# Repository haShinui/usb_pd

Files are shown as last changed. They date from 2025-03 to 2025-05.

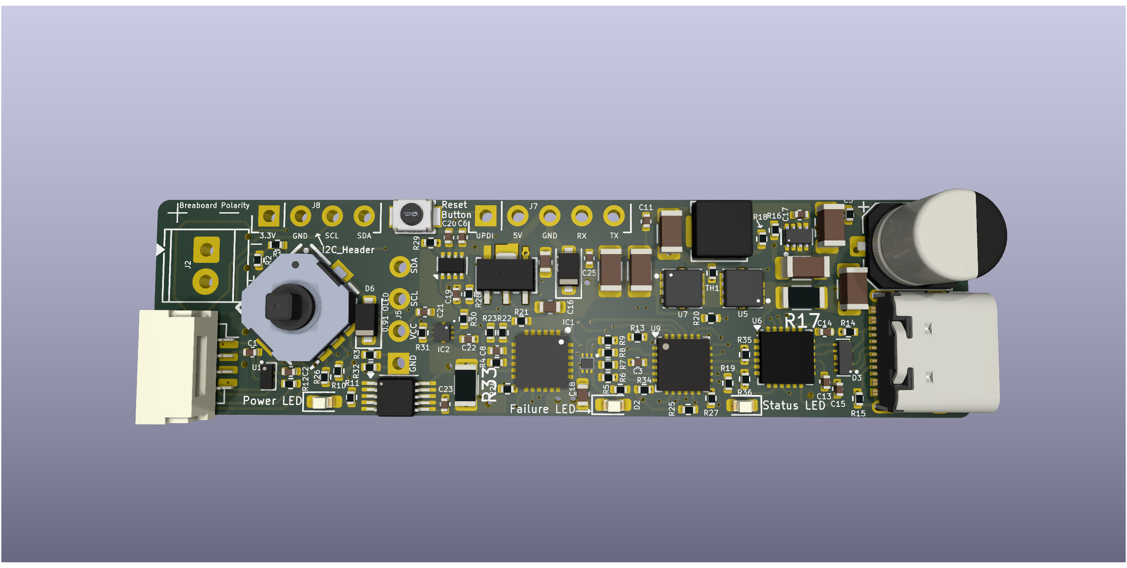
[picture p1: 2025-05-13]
KiCad Files/CYPD3177_DEV_BOARD/pictures/CYPD3177_3.3V_V2_+_OLED(top_no_comps).png

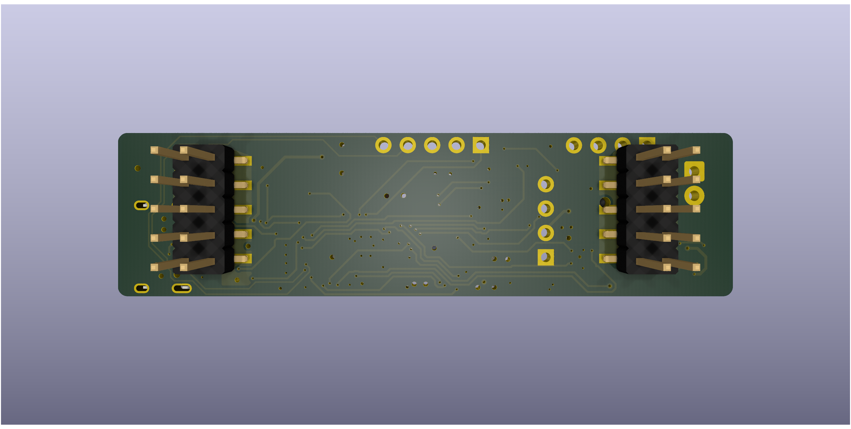
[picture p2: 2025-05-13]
KiCad Files/CYPD3177_DEV_BOARD/pictures/CYPD3177_3.3V_V2_+_OLED(bottom).png

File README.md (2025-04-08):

# BrodBoost-PD
This USB Power Delivery adapter allows to request 20V, 15V, 12V, 9V, or 5V from a compatible power supply, eliminating the need for bulky converters or multiple adapters. A DIP switch selects the desired voltage. The adapter features a power LED, a fault LED, and a screw terminal block for easy wiring. Compatible with standard 2.54 mm breadboards, it provides a simple, compact power solution for prototyping and development.

I documented the process and the design, if you wish to learn more or see earlier versions, I made a short YouTube Video bellow

https://www.youtube.com/watch?v=EAl_JSd1YsA

BrodBoost-PD is an open-source project of Axiometa. Device is available for purchase on the [official website](https://axiometa.ai/product/brodboost-pd/)

PD

# Overview

pdp_top-1

# Device Configurations
BrodBoost-PD can be acquired and/or assembled in essentially three majors ways.

1. No breadboard rails, No Screw Terminal - Great for compact and intergrated solutions.
2. No Breadboard rail, Screw Terminal - Great for all solutions, requires no soldering.
3. Breadboard rails, Screw Terminal - Amazinf for breadboards, allows prototyping and attaching some loads on terminal



# Breadboard Compatibility
In the case of attached headers,the device becomes compatible with almost all BB400 & BB800 Solderless Breadboards

compatibility_pdp1

# Voltage Selection
All voltage rails are connected, that includes both breadboard rails, screw terminal and solder pads. The voltages can be selected through the dip switches in a fashion shown bellow.

wdqqwd

# Schematic
A USB-C receptacle accepts a USB-C cable, with CC1 and CC2 pins connected to the CYPD3177. USB data lines are broken out to a header, while the power rails are managed through a MOSFET bridge, also controlled by the CYPD3177.
When a compatible USB-C cable is connected, the CYPD3177 communicates with the power source and requests a voltage based on the DIP switch-selected reference voltage. Available options include 20V, 15V, 12V, 9V, and 5V.
Current is fixed at 2A, as requested current does not enforce actual current delivery, making adjustable current selection unnecessary. I2C connections have been removed to save space and BOM cost, as they offer little added value for this application.



# PCB Design

BrodBoost-PD is a 4-layer PCB measuring 11.4 mm by 54.0 mm, designed to maximize trace width, thermal performance and interfere as minimally as possible to the power lines. This layout comfortably supports the nominal device current of approximately 4-5 A @ 20V.









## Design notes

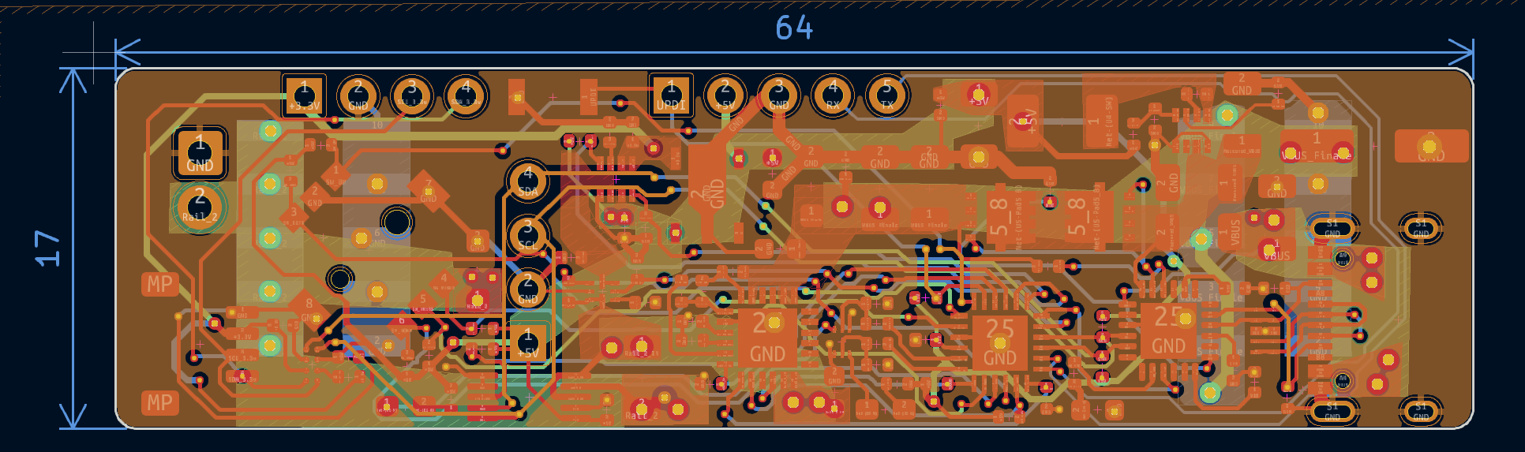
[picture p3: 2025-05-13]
KiCad Files/CYPD3177_DEV_BOARD/pictures/Screenshot 2025-05-13 152529.png

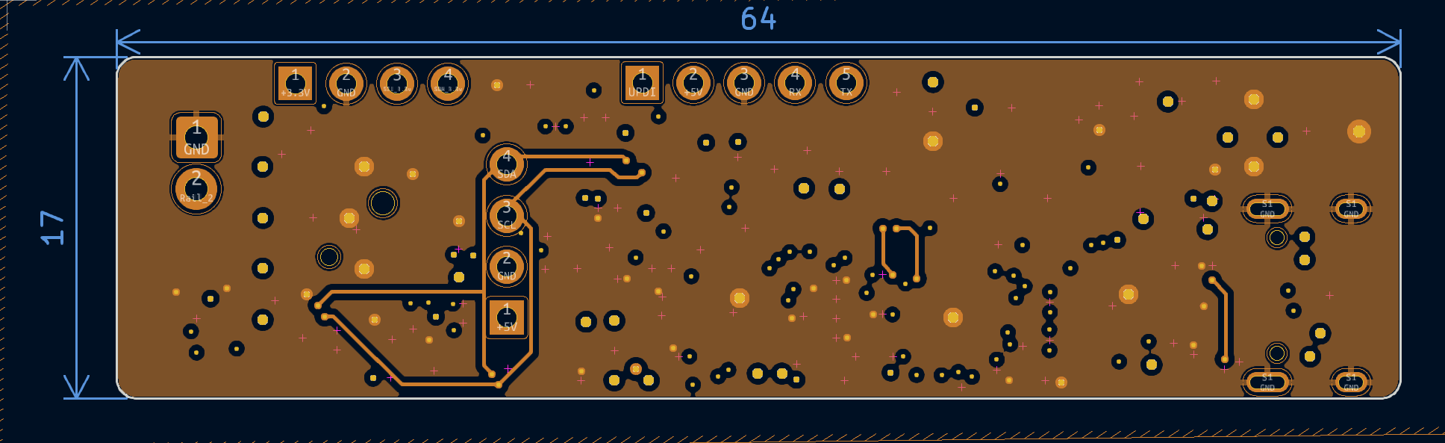
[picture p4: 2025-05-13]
KiCad Files/CYPD3177_DEV_BOARD/pictures/Screenshot 2025-05-13 152450.png

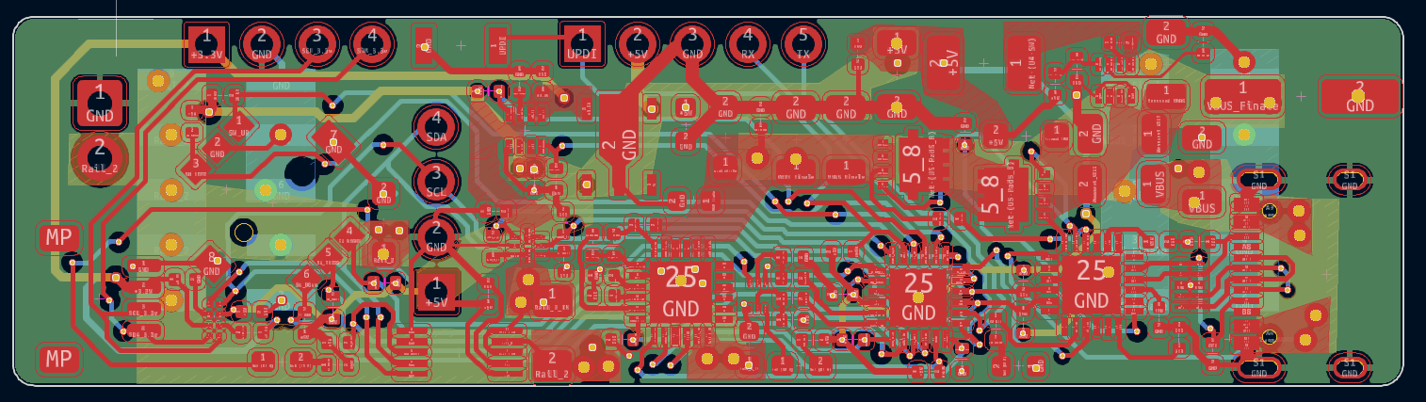
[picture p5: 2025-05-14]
KiCad Files/CYPD3177_DEV_BOARD/pictures/new_v2/Screenshot 2025-05-14 234856.png

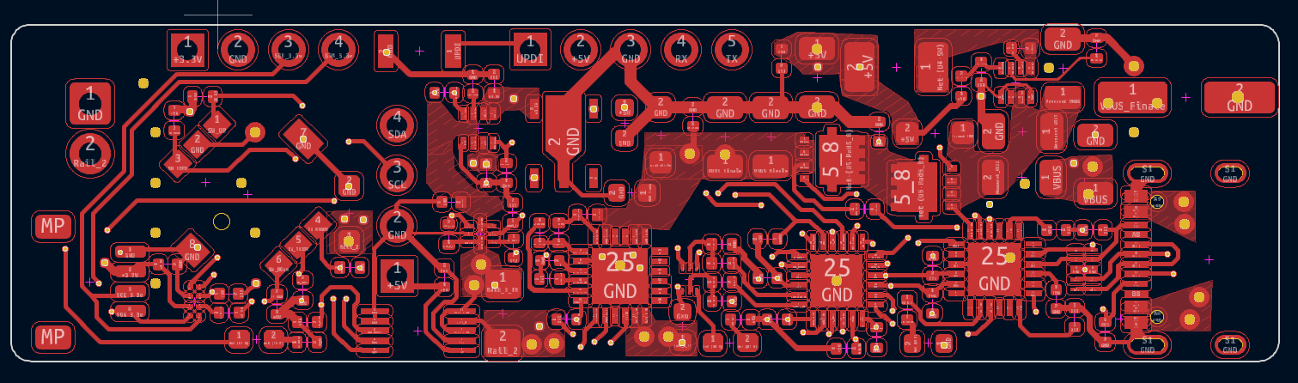
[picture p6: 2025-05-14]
KiCad Files/CYPD3177_DEV_BOARD/pictures/new_v2/Screenshot 2025-05-14 234923.png

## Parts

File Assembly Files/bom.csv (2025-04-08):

Designator | Footprint | Quantity | Value | LCSC Part #
C1, C4 | 603 | 2 | 3.3 uF | C5360803
C10, C11, C13, C2, C9 | 402 | 5 | 1uF | C52923
C12 | 402 | 1 | 100nF | C1525
C3 | 603 | 1 | 0.1 uF | C14663
D1 | 603 | 1 | Green | C2288
D2 | D_SOD-323F | 1 | 15V | C891582
D3 | 603 | 1 | Red | C2286
IC1 | CYPD3177 | 1 | CYPD3177 | C2959321
J1, J2 | PinHeader_2x03_P2.54mm_Vertical_SMD | 2 | Conn_02x02_Counter_Clockwise | C3294461
J4 | TerminalBlock_4Ucon_1x02_P3.50mm_Vertical | 1 | Conn_01x02_Pin
J6 | PinHeader_1x04_P2.54mm_Horizontal | 1 | Output
N21 | PinSocket_1x02_P2.54mm_Vertical_SMD_Pin1Left | 1 | Conn_01x02_Pin
P1 | USB_C_Receptacle_HRO_TYPE-C-31-M-12 | 1 | USB Type C | C2927038
Q2, Q3 | Diodes_PowerDI3333-8 | 2 | DMP3013 | C264098
R10, R17, R1 | 402 | 2 | 1k | C11702
R11 | 402 | 1 | 2k | C4109
R16, R18, R20, R21, R30 | 402 | 5 | 5.1k | C25905
R19, R31 | 402 | 2 | 2.4k | C25882
R4, R8 | 402 | 2 | 10k | C25744
R9 | 402 | 1 | 49.9k | C25897
SW1 | SW_DIP_SPSTx05_Slide_9.78x14.88mm_W8.61mm_P2.54mm | 1 | SW_DIP_x05 | C7471375

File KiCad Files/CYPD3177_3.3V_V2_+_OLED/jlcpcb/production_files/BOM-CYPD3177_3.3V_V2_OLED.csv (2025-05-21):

Comment | Designator | Footprint | LCSC | Quantity
AON7534 | U5,U7 | TRANS_AON7408 | C115844 | 2
1k | R19 | R_0402_1005Metric | C11702 | 1
22uF | C10 | C_1206_3216Metric | C12891 | 1
10uF | C12,C24,C27,C28,C7 | C_1206_3216Metric | C13585 | 5
330k | R21 | R_0402_1005Metric | C138006 | 1
27R | R20 | R_0402_1005Metric | C138021 | 1
TPD4E05U06DQAR | D3 | IC_TPD4E05U06DQAR | C138714 | 1
1nF | C22 | C_0402_1005Metric | C1523 | 1
100nf | C23 | C_0402_1005Metric | C1525 | 1
22nF | C8 | C_0402_1005Metric | C1532 | 1
1u | C14,C16,C18 | C_0402_1005Metric | C15849 | 3
QWIIC | J6 | JST_SH_SM04B-SRSS-TB_1x04-1MP_P1.00mm_Horizontal | C160404 | 1
3.3u | L1 | L_Changjiang_FXL0420 | C167207 | 1
TPS16630RGER | IC1 | QFN50P400X400X100-25N | C1850279 | 1
Power LED | D1 | LED_0603_1608Metric_Pad1.05x0.95mm_HandSolder | C205450 | 1
TPS2117DRL | U8 | SOT-583-8 | C22399676 | 1
Failure LED | D2 | LED_0603_1608Metric_Pad1.05x0.95mm_HandSolder | C2286 | 1
Status LED | D4 | LED_0603_1608Metric | C2290 | 1
B3U-1000P | SW2 | KEY-SMD_B3U-1000PM | C231329 | 1
4.7uF | C6 | C_0402_1005Metric | C23733 | 1
100Ω | R7,R8 | R_0402_1005Metric | C25076 | 2
470Ω | R11,R5 | R_0402_1005Metric | C25117 | 2
10k | R1,R10,R12,R13,R16,R2,R24,R25,R26,R28,R29,R3,R30,R31,R32,R34,R35,R36,R6,R9 | R_0402_1005Metric | C25744 | 20
150k | R22 | R_0402_1005Metric | C25755 | 1
20k | R23 | R_0402_1005Metric | C25765 | 1
22k | R27 | R_0402_1005Metric | C25768 | 1
3.3k | R4 | R_0402_1005Metric | C25890 | 1
5.1k | R14,R15 | R_0402_1005Metric | C25905 | 2
52.3k | R18 | R_0402_1005Metric | C26982 | 1
100uf_35V | C26 | CP_Elec_6.3x7.7 | C2836437 | 1
USB_C_USB2.0_14P | J1 | USB_C_Receptacle_XKB_U262-16XN-4BVC11 | C2848971 | 1
INA237 | U2 | VSSOP-10_3x3mm_P0.5mm | C2864837 | 1
TCA9406YZPR | U1 | TCA9406 | C2871137 | 1
5m | R17,R33 | R_1206_3216Metric | C2988648 | 2
XC6220B331PR-G | U3 | SOT-89-5_TOR | C3013658 | 1
GT-TC0060-H050-L1 | SW1 | SW-SMD_GT-TC0060-H050-L1 | C3019726 | 1
100nF | C1,C11,C13,C15,C17,C2,C20,C25,C3 | C_0402_1005Metric | C307331 | 9
TPS62933PDRLR | U4 | SOFL50P160X60-8N | C3200405 | 1
TPS22992SRXNR | IC2 | TPS22992SRXNR | C3229354 | 1
1uF | C19 | C_0402_1005Metric | C513774 | 1
1uF | C21 | C_0402_1005Metric | C6119811 | 1
ATtiny3217-M | U9 | QFN-24-1EP_4x4mm_P0.5mm_EP2.6x2.6mm | C617969 | 1
Thermistor_NTC_10k_0402 | TH1 | R_0402_1005Metric | C77131 | 1
Conn_01x02_Pin | J2 | TerminalBlock_TE_282834-2_1x02_P2.54mm_Horizontal | C918120 | 1
10uF | C4 | C_0603_1608Metric | C96446 | 1
PMEG6020ER | D5,D6,D7 | D_SOD-123F | C98663 | 3
AP33772S | U6 | QFN-24-1EP_4x4mm_P0.5mm_EP2.65x2.65mm | C9900152998 | 1
Conn_01x05 | J7 | PinHeader_1x05_P2.54mm_Vertical |  | 1
0.91 OLED | J5 | SSD1306-0.91-OLED-4pin-128x32 |  | 1
2N7002DW | Q1 | SOT-363_SC-70-6 |  | 1
I2C_3.3V | J8 | PinHeader_1x04_P2.54mm_Vertical |  | 1
Conn_02x05_Odd_Even | J4 | PinHeader_2x05_P2.54mm_Vertical_SMD |  | 1
Conn_02x05_Odd_Even | J3 | PinHeader_2x05_P2.54mm_Vertical_SMD |  | 1

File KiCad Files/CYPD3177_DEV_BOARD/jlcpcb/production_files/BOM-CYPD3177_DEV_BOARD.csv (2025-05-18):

Comment | Designator | Footprint | LCSC | Quantity
52.3k | R18,R21,R22,R23,R27,R4 | R_0805_2012Metric | C103091 | 6
27R | R20 | R_0805_2012Metric | C138021 | 1
100nF | C1,C11,C13,C15,C17,C2,C23,C25 | C_0805_2012Metric | C1525 | 8
1uF | C14,C3 | C_0805_2012Metric | C15849 | 2
Status LED | D4 | LED_0805_2012Metric | C2286 | 1
B3U-1000P | SW2 | KEY-SMD_B3U-1000PM | C231329 | 1
10k | R1,R10,R12,R13,R16,R2,R24,R25,R26,R28,R29,R3,R30,R31,R32,R34,R35,R36,R6,R7,R8,R9 | R_0805_2012Metric | C25744 | 22
5.1k | R14,R15,R19 | R_0805_2012Metric | C25905 | 3
GT-TC0060-H050-L1 | SW1 | SW-SMD_GT-TC0060-H050-L1 | C3019726 | 1
22uF | C10,C12,C24,C27,C28 | C_1206_3216Metric | C45783 | 5
1uF | C16,C18,C19,C20,C21,C22,C6,C7,C8 | C_0805_2012Metric | C513774 | 9
5m | R17 | R_1206_3216Metric | C728267 | 1
NTC | TH1 | R_0402_1005Metric | C77131 | 1
AP33772S | U6 | QFN-24-1EP_4x4mm_P0.5mm_EP2.65x2.65mm | C9900152998 | 1
3.3u power inductor | L1 | L_Changjiang_FXL0420 |  | 1
TPS62933PDRLR | U4 | SOFL50P160X60-8N |  | 1
Status for Logic selection | J18 | PinSocket_1x01_P2.54mm_Vertical |  | 1
470Ω | R11 | R_0805_2012Metric |  | 1
Conn_01x02_Pin | J2 | TerminalBlock_TE_282834-2_1x02_P2.54mm_Horizontal |  | 1
CC2 | J9 | PinSocket_1x01_P2.54mm_Vertical |  | 1
Logic_swtich | J17 | PinSocket_1x01_P2.54mm_Vertical |  | 1
470Ω | R5 | R_0805_2012Metric |  | 1
Failure LED | D2 | LED_0805_2012Metric |  | 1
ATtiny3217 | U9 | QFN-24-1EP_4x4mm_P0.5mm_EP2.6x2.6mm |  | 1
USB_C_USB2.0_14P | J1 | USB_C_Receptacle_XKB_U262-16XN-4BVC11 |  | 1
AON7534 | U5 | TRANS_AON7408 |  | 1
Logic_report | J20 | PinSocket_1x01_P2.54mm_Vertical |  | 1
Power LED | D1 | LED_0805_2012Metric |  | 1
TPS22992SRXNR | IC2 | TPS22992SRXNR |  | 1
0.91 OLED | J5 | SSD1306-0.91-OLED-4pin-128x32 |  | 1
AP33 interrupt | J10 | PinSocket_1x01_P2.54mm_Vertical |  | 1
Test | J15 | PinSocket_1x01_P2.54mm_Vertical |  | 1
100uf_35V | C26 | CP_Elec_6.3x7.7 |  | 1
I2C_3.3V | J8 | PinHeader_1x04_P2.54mm_Vertical |  | 1
10uF | C4 | C_0805_2012Metric |  | 1
TPS2117 | U8 | SOT-583-8 |  | 1
VBUS_Fault | J16 | PinSocket_1x01_P2.54mm_Vertical |  | 1
AON7534 | U7 | TRANS_AON7408 |  | 1
PMEG6020ER | D7 | D_SOD-123F |  | 1
Conn_01x05 | J7 | PinHeader_1x05_P2.54mm_Vertical |  | 1
Buck_Status | J23 | PinSocket_1x01_P2.54mm_Vertical |  | 1
TCA9406 | U1 | TCA9406 |  | 1
TPS16630RGER | IC1 | QFN50P400X400X100-25N |  | 1
SDA | J13 | PinSocket_1x02_P2.54mm_Vertical |  | 1
Alert INA237 | J22 | PinSocket_1x01_P2.54mm_Vertical |  | 1
INA237 | U2 | VSSOP-10_3x3mm_P0.5mm |  | 1
PMEG6020 | D5 | D_SOD-123F |  | 1
Logic_Selection | J19 | PinSocket_1x01_P2.54mm_Vertical |  | 1
PMEG6020ER | D6 | D_SOD-123F |  | 1
5mΩ | R33 | L_1206_3216Metric_Pad1.42x1.75mm_HandSolder |  | 1
NTC | J11 | PinSocket_1x01_P2.54mm_Vertical |  | 1
2N7002DW | Q1 | SOT-363_SC-70-6 |  | 1
XC6220B331 | U3 | SOT-89-5_TOR |  | 1
CC1 | J6 | PinSocket_1x01_P2.54mm_Vertical |  | 1
5V | J14 | PinSocket_1x01_P2.54mm_Vertical |  | 1
TPD4E05U06 | D3 | IC_TPD4E05U06DQAR |  | 1
GND | J21 | PinSocket_1x01_P2.54mm_Vertical |  | 1
GND | J12 | PinSocket_1x01_P2.54mm_Vertical |  | 1

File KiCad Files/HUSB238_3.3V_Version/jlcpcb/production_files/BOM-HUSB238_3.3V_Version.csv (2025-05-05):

Comment | Designator | Footprint | LCSC | Quantity
17.8kΩ | R18 | R_0402_1005Metric_Pad0.72x0.64mm_HandSolder | C129766 | 1
10uF | C11,C9 | C_0402_1005Metric_Pad0.74x0.62mm_HandSolder | C194427 | 2
Green Power LED | D8 | LED_0603_1608Metric_Pad1.05x0.95mm_HandSolder | C205450 | 1
AO3400A | Q9 | SOT-23 | C20917 | 1
150Ω | R22 | R_0402_1005Metric_Pad0.72x0.64mm_HandSolder | C25082 | 1
220Ω | R25 | R_0402_1005Metric_Pad0.72x0.64mm_HandSolder | C25091 | 1
100kΩ | R29 | R_0402_1005Metric_Pad0.72x0.64mm_HandSolder | C25741 | 1
10kΩ | R12,R15,R31 | R_0402_1005Metric_Pad0.72x0.64mm_HandSolder | C25744 | 3
13.7kΩ | R27 | R_0402_1005Metric_Pad0.72x0.64mm_HandSolder | C25854 | 1
49.9kΩ | R14 | R_0402_1005Metric_Pad0.72x0.64mm_HandSolder | C25897 | 1
5.1kΩ | R13 | R_0402_1005Metric_Pad0.72x0.64mm_HandSolder | C25905 | 1
NCP1117-3.3_SOT223 | U2 | SOT-223-3_TabPin2 | C26537 | 1
USB_C_Receptacle_USB2.0_14P | J9 | USB_C_Receptacle_XKB_U262-16XN-4BVC11 | C2988369 | 1
31.6 kΩ | R26 | R_0402_1005Metric_Pad0.72x0.64mm_HandSolder | C2998091 | 1
1uF | C12,C3,C4,C5,C6 | C_0402_1005Metric_Pad0.74x0.62mm_HandSolder | C307413 | 5
100nF | C10 | C_0402_1005Metric_Pad0.74x0.62mm_HandSolder | C343047 | 1
AONR21357 | Q2 | TRANS_AONR21307 | C431196 | 1
TPS2121 | U1 | IC_TPS2121RUXR | C485916 | 1
USBLC6 | U4 | SOT-23-6 | C5180249 | 1
5kΩ | R28,R30 | R_0402_1005Metric_Pad0.72x0.64mm_HandSolder | C5948099 | 2
SW_DIP_x05 | SW1 | SW_DIP_SPSTx05_Slide_6.7x14.26mm_W8.61mm_P2.54mm_LowProfile | C7471375 | 1
HUSB238_USB_PD | U3 | DFN-10-1EP_3x3mm_P0.5mm_EP1.55x2.48mm | C7471904 | 1
Red Failure LED | D7 | LED_0603_1608Metric_Pad1.05x0.95mm_HandSolder | C965799 | 1
6.04kΩ | R16 | R_0402_1005Metric_Pad0.72x0.64mm_HandSolder | C97819 | 1

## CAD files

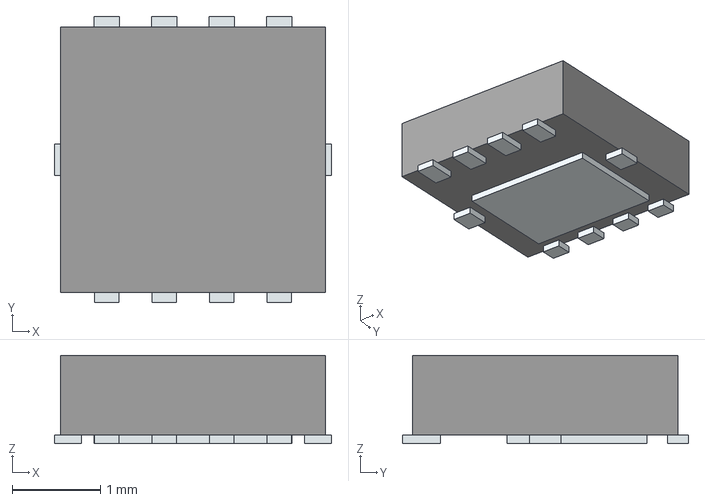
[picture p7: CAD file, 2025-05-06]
KiCad Files/CYPD3177_DEV_BOARD/AON7534/AON7534.stp
3.13 x 3.24 x 1.00 mm
Pins

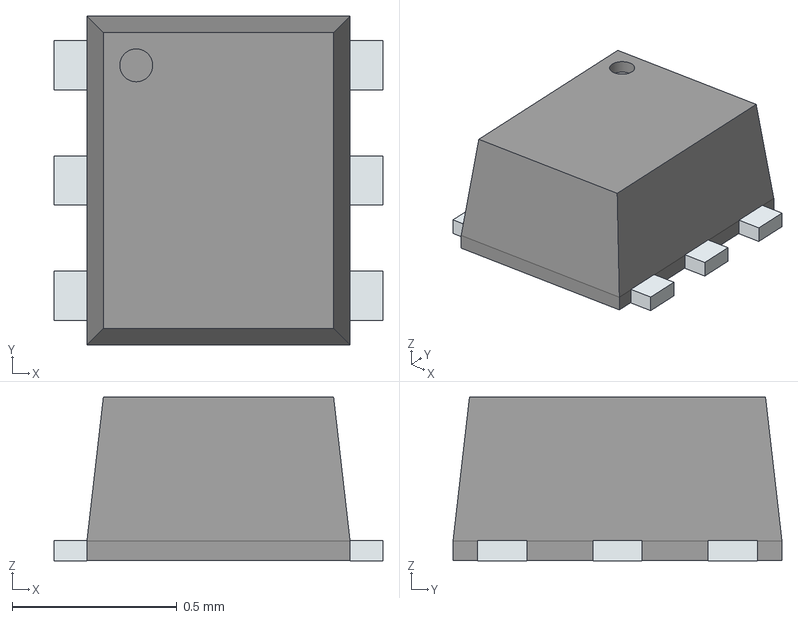
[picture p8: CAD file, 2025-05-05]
KiCad Files/CYPD3177_DEV_BOARD/DMC2990UDJ/DMC2990UDJ-7.stp
1.00 x 1.00 x 0.498 mm
PinsArrayL
PinsArrayR

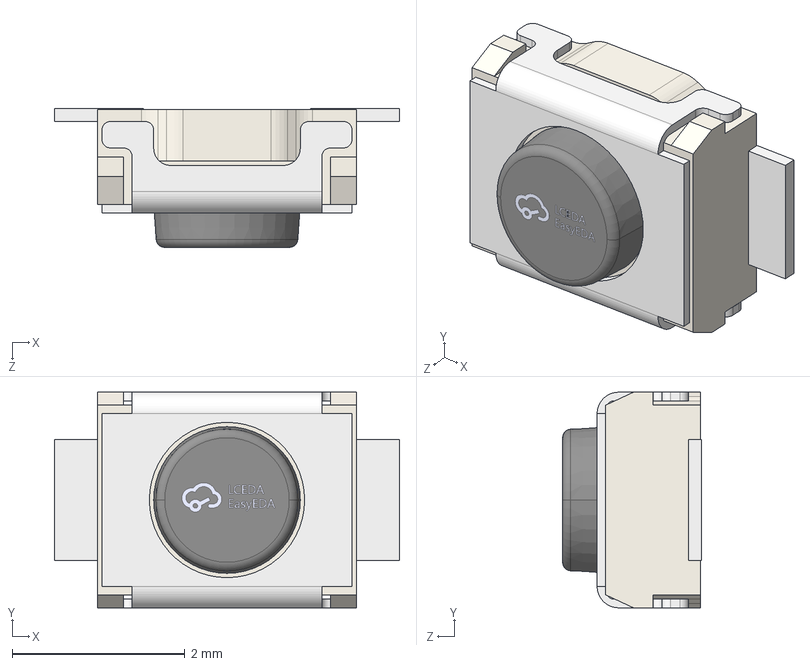
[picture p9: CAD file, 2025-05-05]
KiCad Files/CYPD3177_DEV_BOARD/Mini_Switch/KEY-SMD_2P-L3.0-W2.5-H1.6-LS4.0.step
4.00 x 2.50 x 1.61 mm

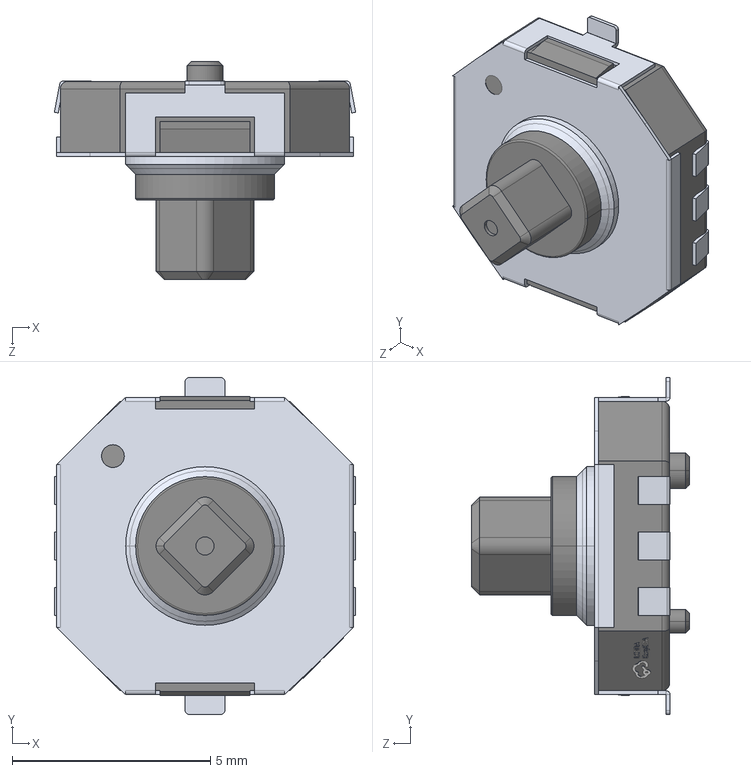
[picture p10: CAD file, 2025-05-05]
KiCad Files/CYPD3177_DEV_BOARD/tc006/SW-SMD_GT-TC0060-H050-L1.step
7.60 x 8.50 x 5.50 mm

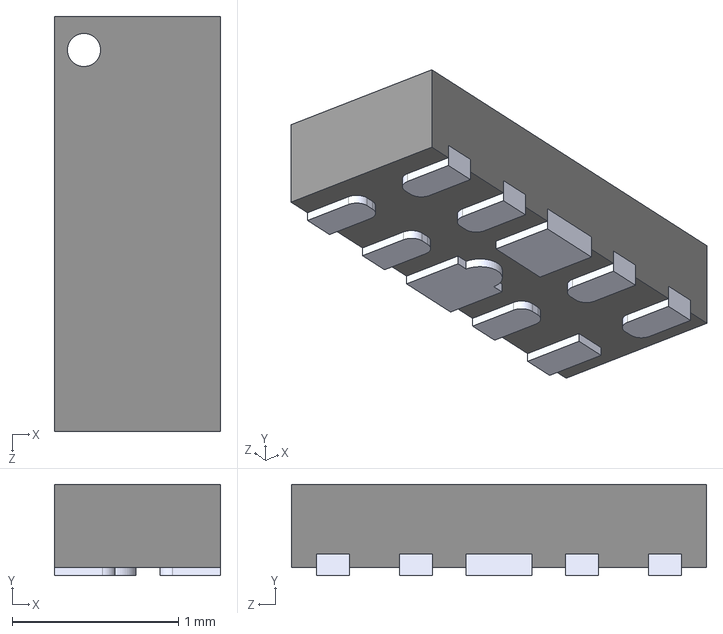
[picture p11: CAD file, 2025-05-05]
KiCad Files/CYPD3177_DEV_BOARD/TPD4E05U06DQAR/TPD4E05U06DQAR.step
1.00 x 0.55 x 2.50 mm

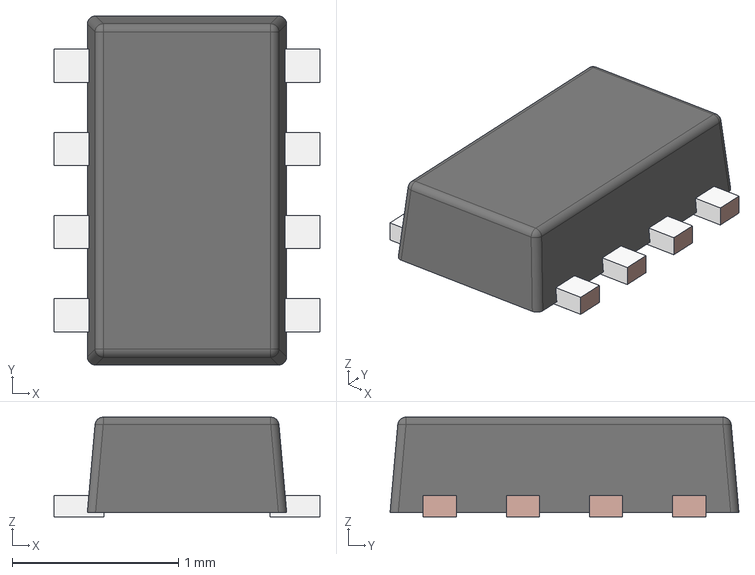
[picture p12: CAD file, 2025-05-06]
KiCad Files/CYPD3177_DEV_BOARD/TPS2117DRL/TPS2117DRLR.stp
1.60 x 2.10 x 0.6 mm
FRAME-DRL0008A
BODY-SOT

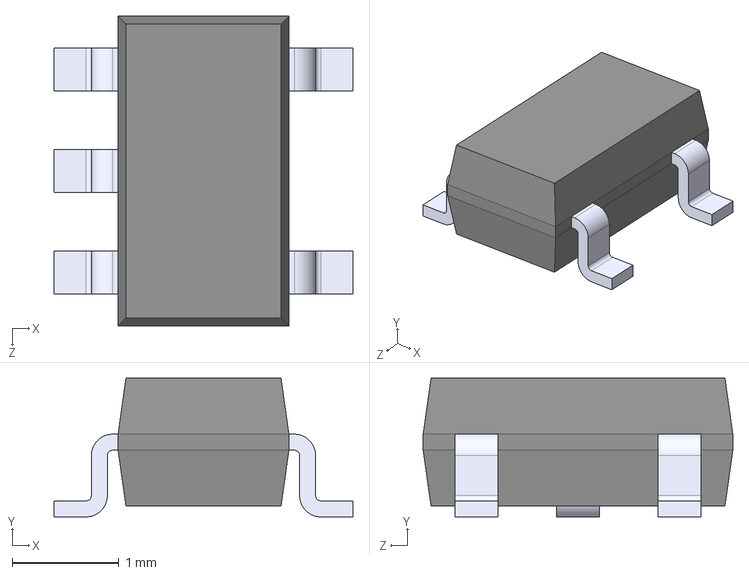
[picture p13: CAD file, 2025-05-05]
KiCad Files/CYPD3177_DEV_BOARD/xc6/XC6220B331MR-G.step
2.80 x 1.30 x 2.90 mm

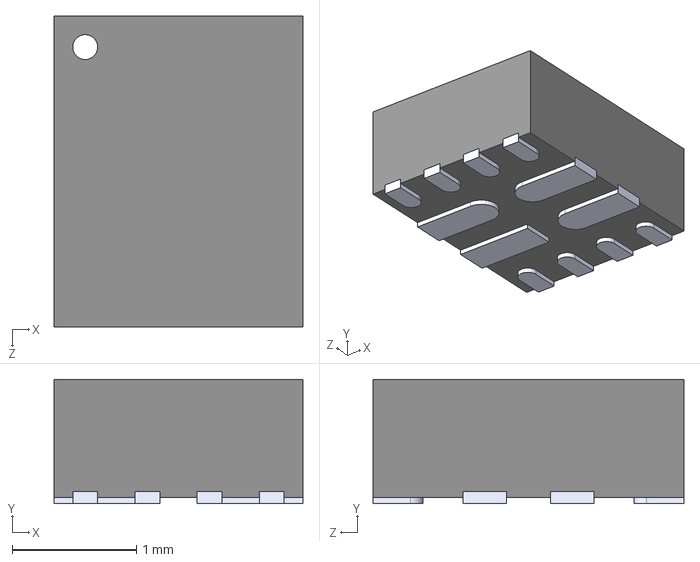
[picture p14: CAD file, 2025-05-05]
KiCad Files/HUSB238_3.3V_Version/tps2121/TPS2121RUXR.step
2.00 x 1.00 x 2.50 mm

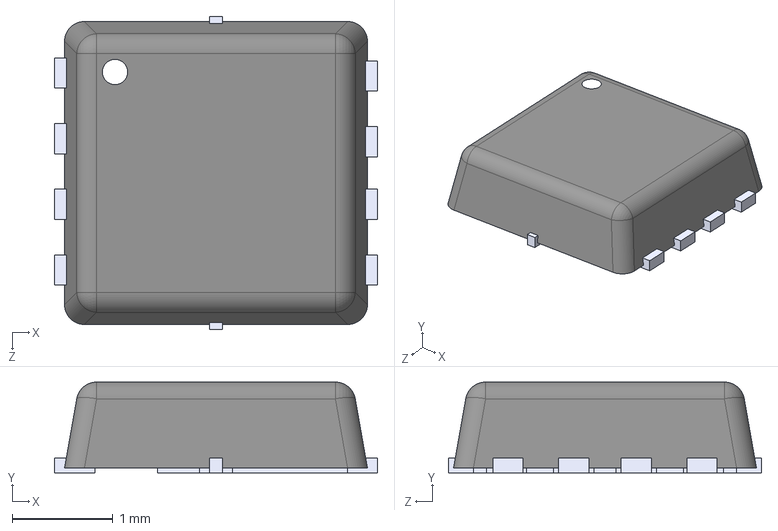
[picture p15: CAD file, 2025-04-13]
KiCad Files/HUSB238_version/AONR21307/AONR21307.step
3.20 x 0.9 x 3.10 mm

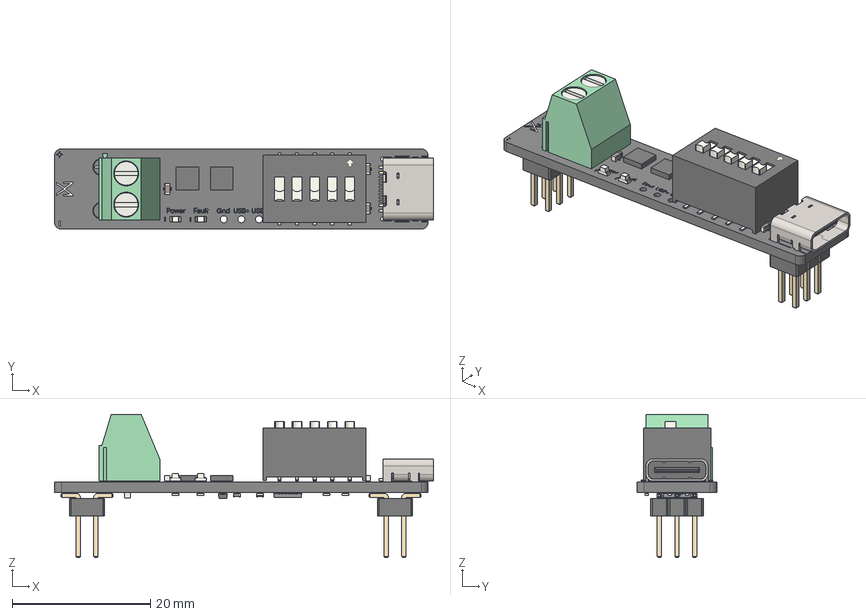
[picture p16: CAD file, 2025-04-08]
Schematics, 3D Model/STP_BrodBoost-PD_Rev3.step
54.8 x 11.6 x 20.7 mm
TerminalBlock_Phoenix_MKDS-1,5-2_1x02_P5.00mm_Horizontal
C_0603_1608Metric x 3
Diodes_PowerDI3333-8 x 2
LED_0603_1608Metric x 2
SW_DIP_SPSTx05_Slide_9.78x14.88mm_W8.61mm_P2.54mm
Type-C 16P
C_0402_1005Metric x 6
R_0402_1005Metric x 14
D_SOD-323F
PinHeader_2x03_P2.54mm_Vertical_SMD x 2
ThermalPin
PinsArrayLR
PinsArrayTB
BrodBoost-PD_silkscreen
BrodBoost-PD_PCB

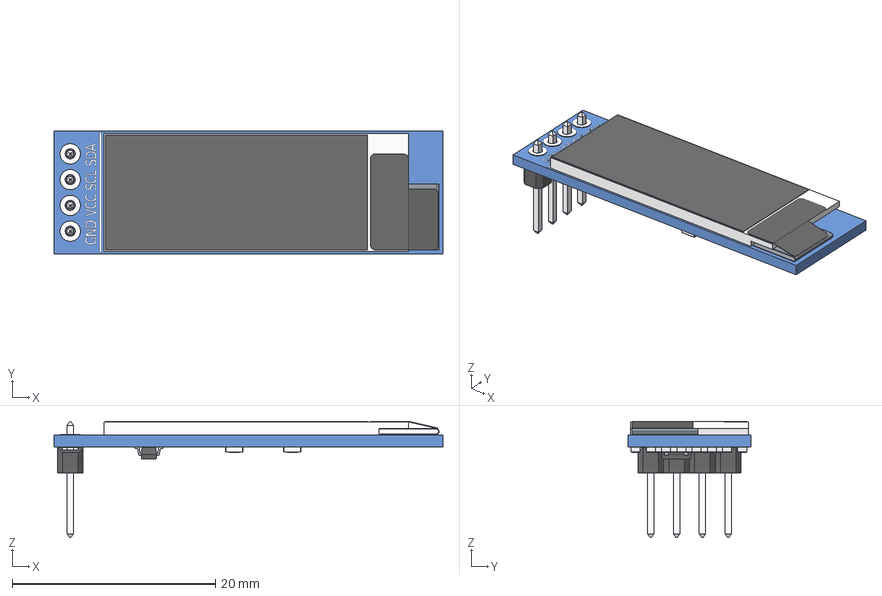
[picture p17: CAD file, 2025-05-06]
KiCad Files/CYPD3177_DEV_BOARD/test/OLED_0.91_128x32.stp
38.3 x 12.1 x 11.5 mm
OLED_0.91_128x32
Pin Header 4 x 1 TH 2.54mm Pitch
RESC-0603 x 13
2SD0601A

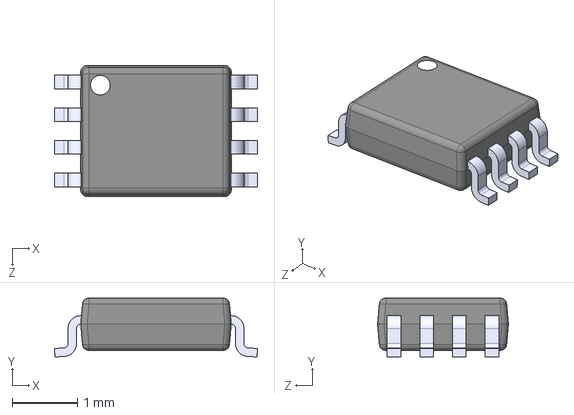
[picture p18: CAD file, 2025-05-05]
KiCad Files/CYPD3177_DEV_BOARD/test/PCA9306DCUR.step
3.10 x 0.9 x 2.00 mm

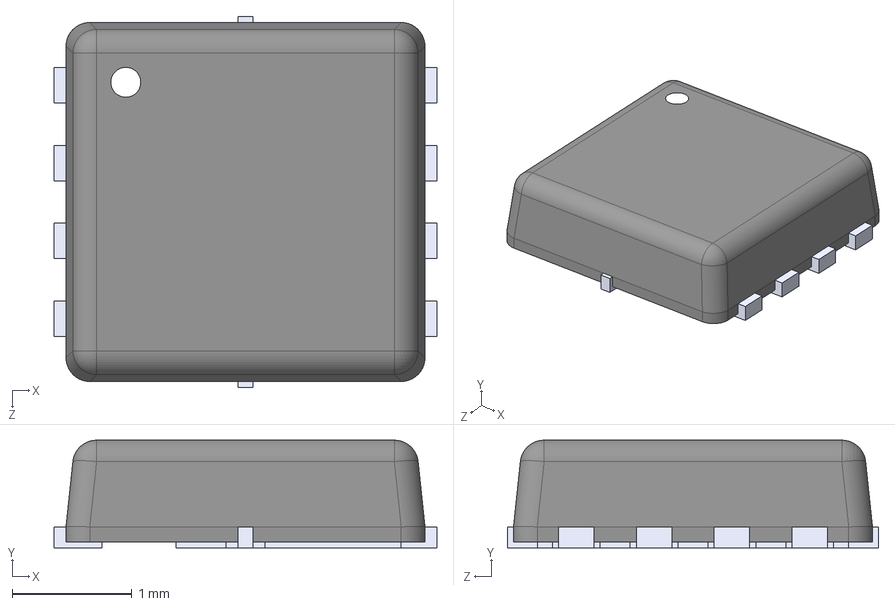
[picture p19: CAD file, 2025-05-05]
KiCad Files/CYPD3177_DEV_BOARD/test/AON7534.step
3.20 x 0.9 x 3.10 mm

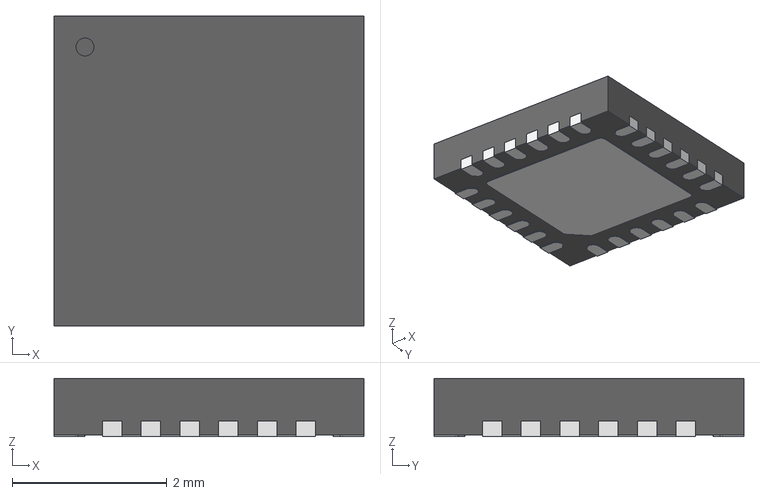
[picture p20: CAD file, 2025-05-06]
KiCad Files/CYPD3177_DEV_BOARD/test/AP33772SDKZ-13-FA01.stp
4.00 x 4.00 x 0.75 mm

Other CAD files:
KiCad Files/CYPD3177_DEV_BOARD/TPS16630/TPS16630RGER.STEP
KiCad Files/CYPD3177_DEV_BOARD/TPS22992S/TPS22992SRXNR--3DModel-STEP-56544.STEP
KiCad Files/CYPD3177_DEV_BOARD/TPS26633RGET/TPS26633RGET.step
KiCad Files/CYPD3177_DEV_BOARD/TPS62933PDRLR/TPS62933PDRLR.step

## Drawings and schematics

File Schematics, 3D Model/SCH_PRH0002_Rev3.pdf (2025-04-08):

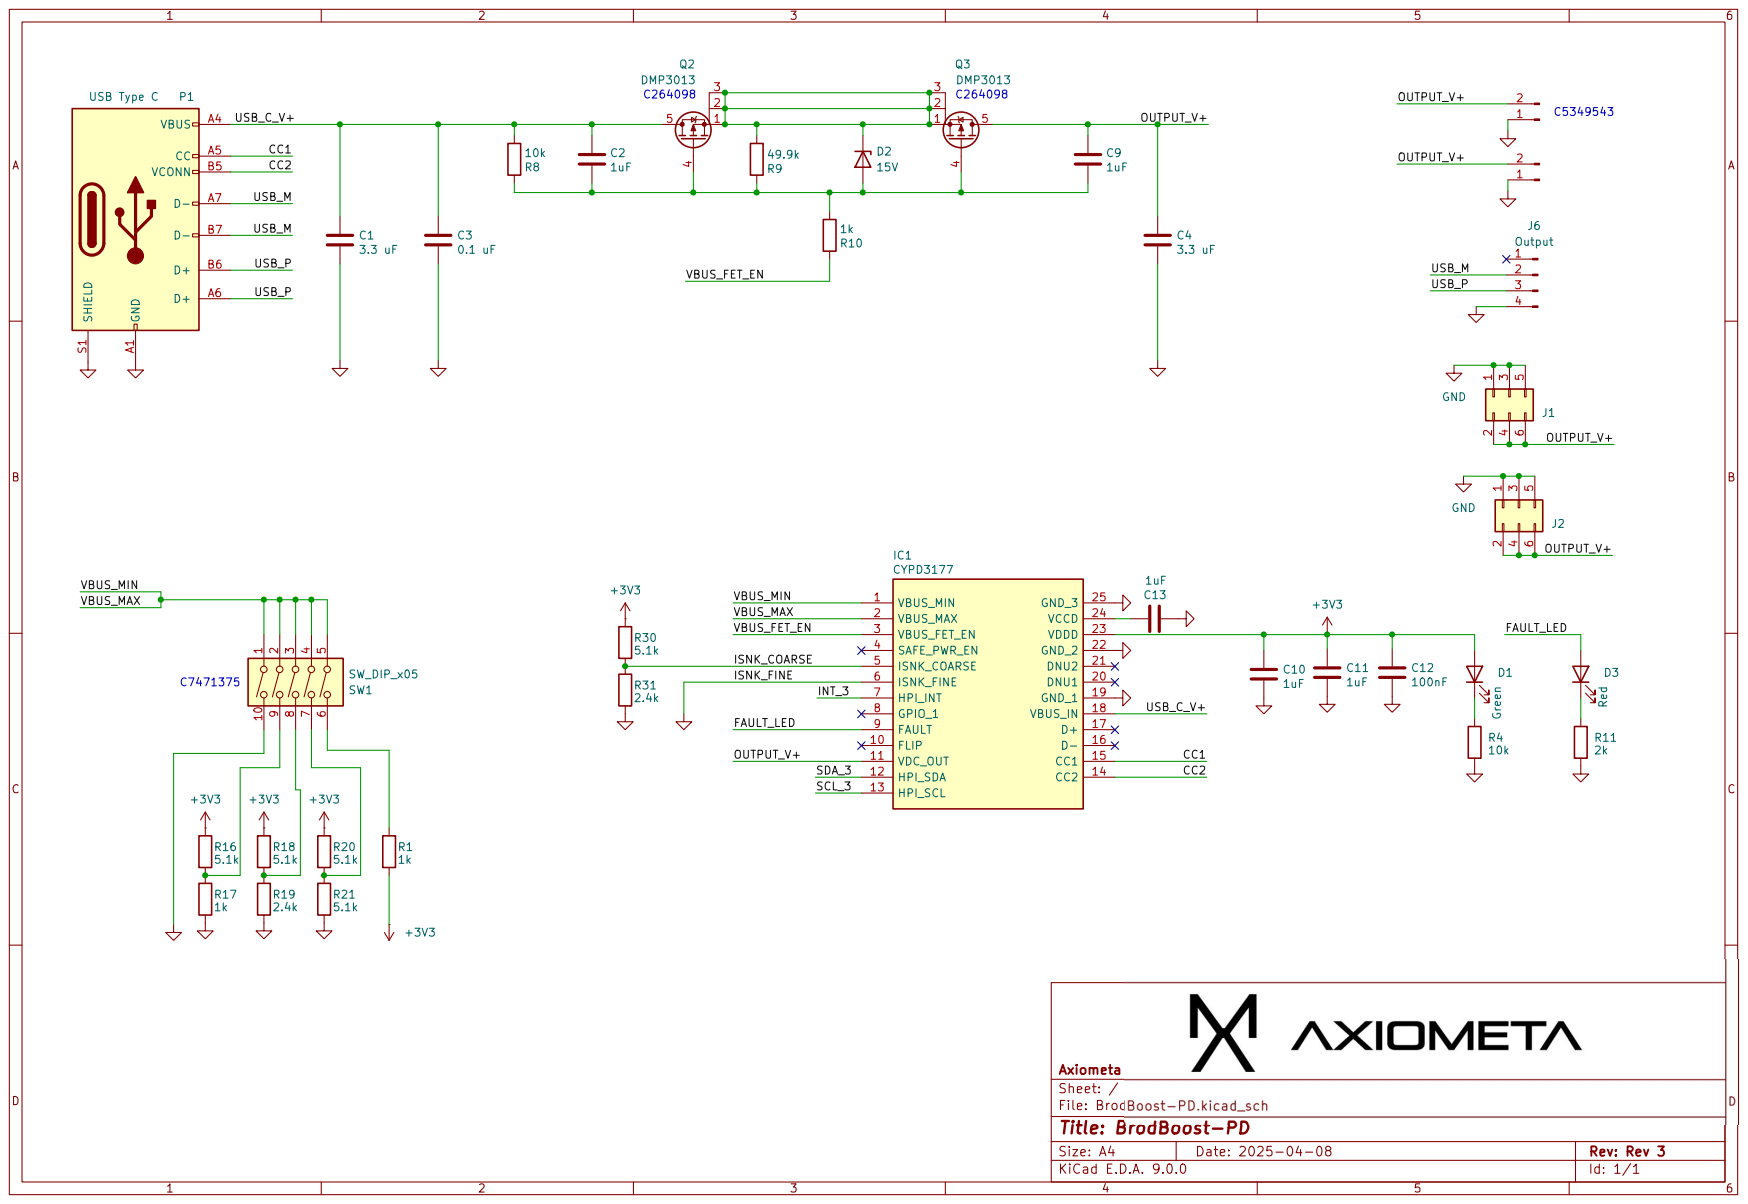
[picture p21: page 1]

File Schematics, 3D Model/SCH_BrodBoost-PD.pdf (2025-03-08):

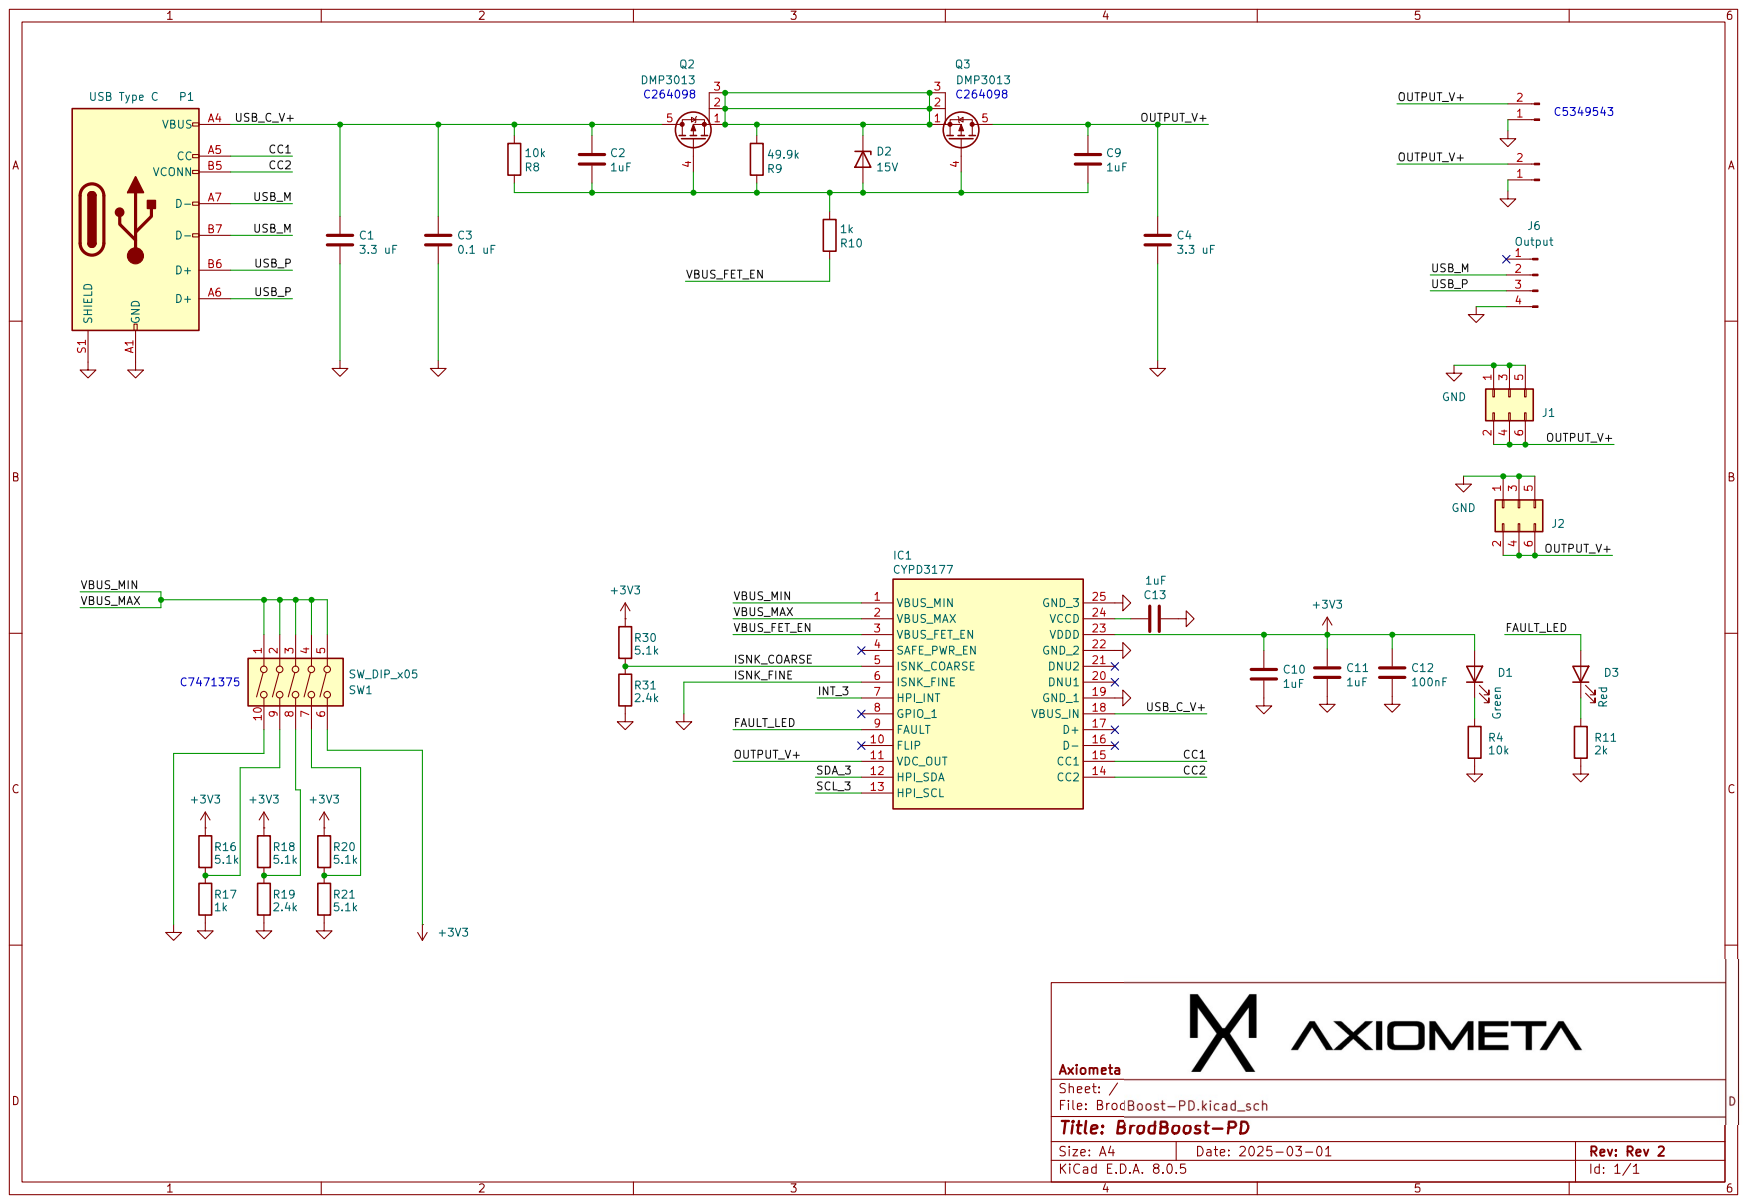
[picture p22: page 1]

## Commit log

2025-03-08 added BOM
    [BOM_BrodBoost-PD.xls]
2025-03-08 added kicad files
2025-04-10 deisng changes
    [HUSB238_version.kicad_pcb, HUSB238_version.kicad_sch]
2025-04-11 changed pcb
    [HUSB238_version.kicad_sch]
2025-04-13 almost finished husb238 version
    [AONR21307.step, BrodBoost-PD.kicad_pcb, HUSB238_version.kicad_pcb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]
2025-05-05 many changes and new pcb design. Also updated husb238 design after boards arraived
    [AON7534.step, BOM-CYPD3177_3.3V_V2_+_OLED.csv, BOM-HUSB238_3.3V_Version.csv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]
2025-05-06 schematics done
    [AON7534.stp, AP33772SDKZ-13-FA01.stp, CYPD3177_3.3V_V2_+_OLED.kicad_pcb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]
2025-05-06 major cahnges do desing, now think final design before designing pcb
    [CYPD3177_3.3V_V2_+_OLED.kicad_pcb, Logic.kicad_sch, Power.kicad_sch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]
2025-05-06 some changes
    [CYPD3177_3.3V_V2_+_OLED.kicad_pcb, Logic.kicad_sch, Power.kicad_sch]
2025-05-11 CYPD3177 wiring finshed, only silkscreen needs changes and make a breakout board
    [CYPD3177_3-B_Cu.gbl, CYPD3177_3-B_Mask.gbs, CYPD3177_3-B_Paste.gbp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]
2025-05-12 finshed pcb, assigning part numbers
    [CYPD3177_3.3V_V2_+_OLED(before changes to capacitors).kicad_pcb, Logic.kicad_sch, Power.kicad_sch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]
2025-05-13 almost finished
    [CYPD3177_3.3V_V2_+_OLED.kicad_pcb, CYPD3177_3.3V_V2_+_OLED.kicad_sch, Logic.kicad_sch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]
2025-05-14 now final version, changed routing completly and should be better board
    [CYPD3177_3.3V_V2_+_OLED(after schotly & before rewiring v2).kicad_pcb, Logic.kicad_sch, Power.kicad_sch]
2025-05-19 changes final
    [BOM-CYPD3177_3.3V_V2_+_OLED.csv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]
2025-05-19 changed vias to 0.3mm, because cheacper to order on jlpcb. On final order change back to 0.2 or redesign board.
    [CYPD3177_3.3V_V2_+_OLED-CuBottom.gbr, CYPD3177_3.3V_V2_+_OLED-CuIn1.gbr, CYPD3177_3.3V_V2_+_OLED-CuIn2.gbr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]
